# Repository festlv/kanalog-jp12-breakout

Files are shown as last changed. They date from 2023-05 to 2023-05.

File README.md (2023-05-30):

KFlop KAnalog JP12 breakout
==================================

KAnalog board has a connector JP12 with 8 outputs and 8 inputs. Since these IOs are unprotected, 3.3V LVTTL type, they 
are less than suitable for use for general purpose tasks (extra end stops, outputs etc).

This board breaks out these IOs as opto-isolated inputs and outputs, suitable for driving 24V loads and reading 24V inputs.

IO connection follows Kconnect conventions, see optoisolated inputs/outputs section of [this document](http://dynomotion.com/Help/SchematicsKonnect/ConnectorsKonnect.htm).

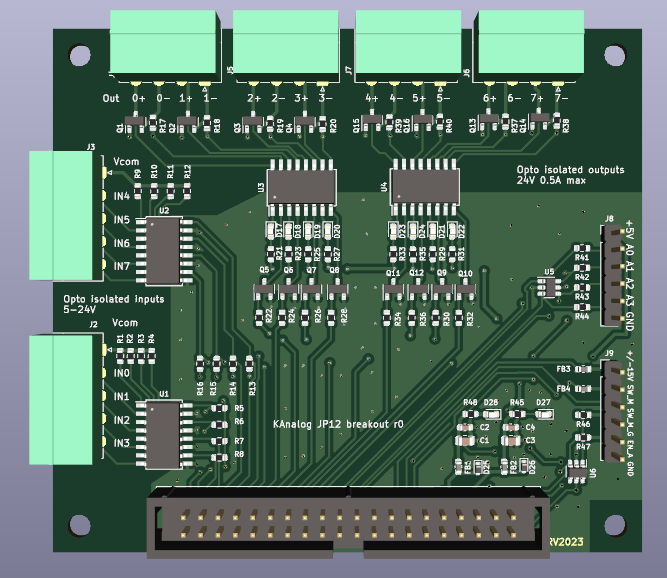
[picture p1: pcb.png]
pcb image


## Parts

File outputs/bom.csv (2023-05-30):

Source: | /home/reinis/Sync/ee/kanalog-jp12-breakout/kanalog-jp12-breakout.kicad_sch
Date: | trešdiena, 2023. gada 31. maijs, 02:11:31
Tool: | Eeschema 7.0.5-4d25ed1034~172~ubuntu20.04.1
Generator: | /usr/share/kicad/plugins/bom_csv_grouped_by_value.py
Component Count: | 99
Collated Components:
Item | Qty | Reference(s) | Value | LibPart | Footprint | Datasheet | DNP | LCSC# | MPN | Manufacturer
1 | 2 | C1, C3 | 10uF | Device:C_Small | Capacitor_SMD:C_0805_2012Metric | ~ |  | C17024 | CL21A106KPFNNNE | Samsung
2 | 2 | C2, C4 | 0.1uF | Device:C_Small | Capacitor_SMD:C_0603_1608Metric | ~
3 | 10 | D17, D18, D19, D20, D21, D22, D23, D24, D27, D28 | LED_GREEN | hadv-ui:LED_GREEN | LED_SMD:LED_0603_1608Metric | ~ |  | C434423 | SZYY0603YG | Yongyu Photoelectric
4 | 1 | D25 | BSD5C031V | hadv-protection:BSD5C031V | Diode_SMD:D_SOD-523 | https://datasheet.lcsc.com/lcsc/1912111437_BORN-BSD5C031V_C151984.pdf |  | C151984 | BSD5C031V | BORN
5 | 1 | D26 | PESD5V0S1BBN | hadv-protection:PESD5V0S1BBN | Diode_SMD:D_SOD-523 | https://datasheet.lcsc.com/lcsc/1912111437_BORN-PESD5V0S1BBN_C314264.pdf |  | C314264 | PESD5V0S1BBN | BORN
6 | 4 | FB1, FB2, FB3, FB4 | FB_100R_3A | hadv-passives:FB_100R_3A | Inductor_SMD:L_0603_1608Metric | ~ |  | C96995 | UPZ1608E101-3R0TF | Sunlord
7 | 1 | J1 | Conn_02x20_Odd_Even | Connector_Generic:Conn_02x20_Odd_Even | Connector_IDC:IDC-Header_2x20_P2.54mm_Vertical | ~ |  | C2962248 | X1270WR-2x20A-6TV01 | XKB
8 | 2 | J2, J3 | TERM-BLK-5H | hadv-connectors:TERM-BLK-5H | Connector_Phoenix_MC:PhoenixContact_MC_1,5_5-G-3.5_1x05_P3.50mm_Horizontal | ~ |  | C441174 | KF2EDGR-3.5-5P | Cixi Kefa Elec
9 | 4 | J4, J5, J6, J7 | TERM-BLK-4H | hadv-connectors:TERM-BLK-4H | Connector_Phoenix_MC:PhoenixContact_MC_1,5_4-G-3.5_1x04_P3.50mm_Horizontal | ~ |  | C441173 | KF2EDGR-3.5-4P | Cixi Kefa Elec
10 | 2 | J8, J9 | Conn_01x06 | Connector_Generic:Conn_01x06 | Connector_PinHeader_2.54mm:PinHeader_1x06_P2.54mm_Vertical | ~
11 | 8 | Q1, Q2, Q3, Q4, Q13, Q14, Q15, Q16 | DSS4240T | hadv-transistors:DSS4240T | Package_TO_SOT_SMD:SOT-23 | https://datasheet.lcsc.com/lcsc/1809081612_Diodes-Incorporated-DSS4240T-7_C151399.pdf |  | C151399 | DSS4240T-7 | Diodes Inc
12 | 8 | Q5, Q6, Q7, Q8, Q9, Q10, Q11, Q12 | SS8050 | hadv-transistors:SS8050 | Package_TO_SOT_SMD:SOT-23 | ~ |  | C2150 | SS8050 | Jiangsu Changjing Electronics
13 | 10 | R1, R2, R3, R4, R9, R10, R11, R12, R45, R48 | 4.12K | Device:R_Small | Resistor_SMD:R_0603_1608Metric | ~ |  | C23041 | 0603WAF4121T5E | Uniroyal
14 | 8 | R5, R6, R7, R8, R13, R14, R15, R16 | 10K | Device:R_Small | Resistor_SMD:R_0603_1608Metric | ~ |  | C25804 | 0603WAF1002T5E | Uniroyal
15 | 8 | R17, R18, R19, R20, R37, R38, R39, R40 | 220R | Device:R_Small | Resistor_SMD:R_0603_1608Metric | ~ |  | C22962 | 0603WAF2200T5E | Uniroyal
16 | 16 | R21, R22, R23, R24, R25, R26, R27, R28, R29, R30, R31, R32, R33, R34, R35, R36 | 330R | Device:R_Small | Resistor_SMD:R_0603_1608Metric | ~ |  | C23138 | 0603WAF3300T5E | Uniroyal
17 | 6 | R41, R42, R43, R44, R46, R47 | 100R | Device:R_Small | Resistor_SMD:R_0603_1608Metric | ~ |  | C22775 | 0603WAF1000T5E | Uniroyal
18 | 4 | U1, U2, U3, U4 | ELQ3H4 | hadv-buffers-translators:ELQ3H4 | Package_SO:SOIC-16W_5.3x10.2mm_P1.27mm | https://datasheet.lcsc.com/lcsc/1810301025_Everlight-Elec-ELQ3H4-TA-G_C150957.pdf |  | C150957 | ELQ3H4(TA)-G | Everlight Elec
19 | 2 | U5, U6 | USBLC6-4SC6 | hadv-protection:USBLC6-4SC6 | Package_TO_SOT_SMD:SOT-23-6 | https://www.st.com/resource/en/datasheet/usblc6-4.pdf |  | C5197386 | USBLC6-4SC6 | TECH PUBLIC

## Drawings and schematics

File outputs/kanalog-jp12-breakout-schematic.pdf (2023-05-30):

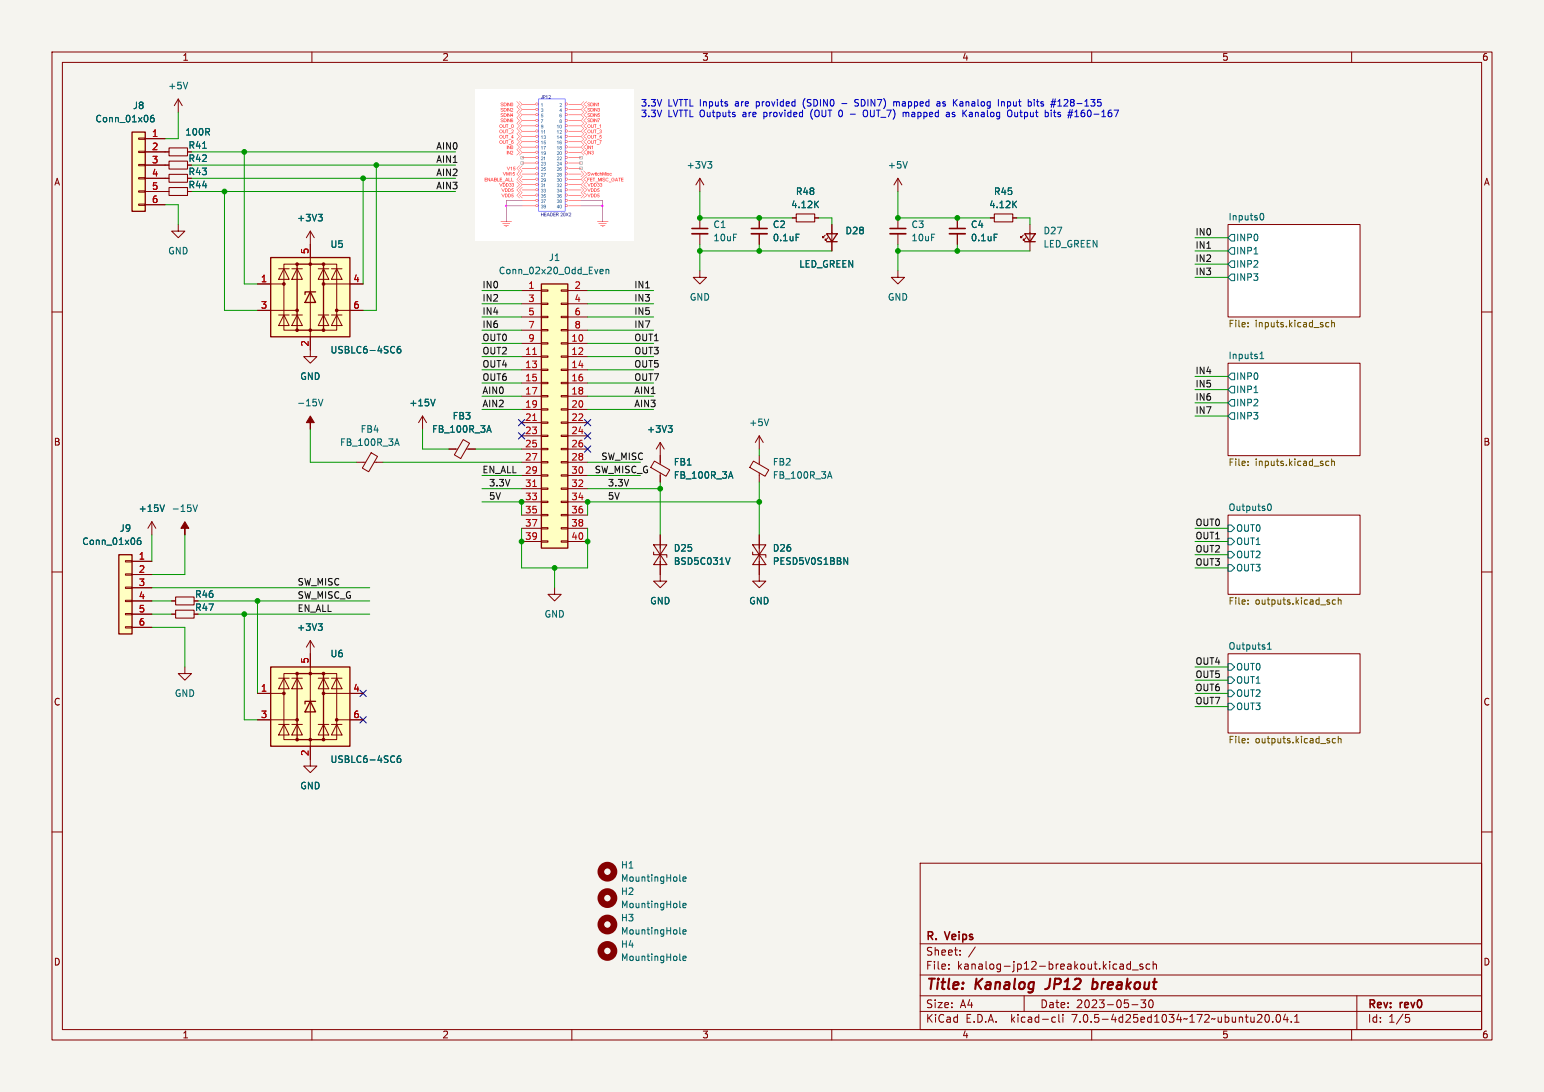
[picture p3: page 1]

3.3V LVTTL Inputs are provided (SDIN0 - SDIN7) mapped as Kanalog Input bits #128-135

Inputs1 File: inputs.kicad_sch OUT0 OUT1 OUT2 OUT3 Outputs0 File: outputs.kicad_sch OUT0 OUT1 OUT2 OUT3 Outputs1 File: outputs.kicad_sch GND

H1 MountingHole H3 MountingHole H2 MountingHole H4 MountingHole

Id: 1/5 Title: Kanalog JP12 breakout File: kanalog-jp12-breakout.kicad_sch Sheet: / R. Veips

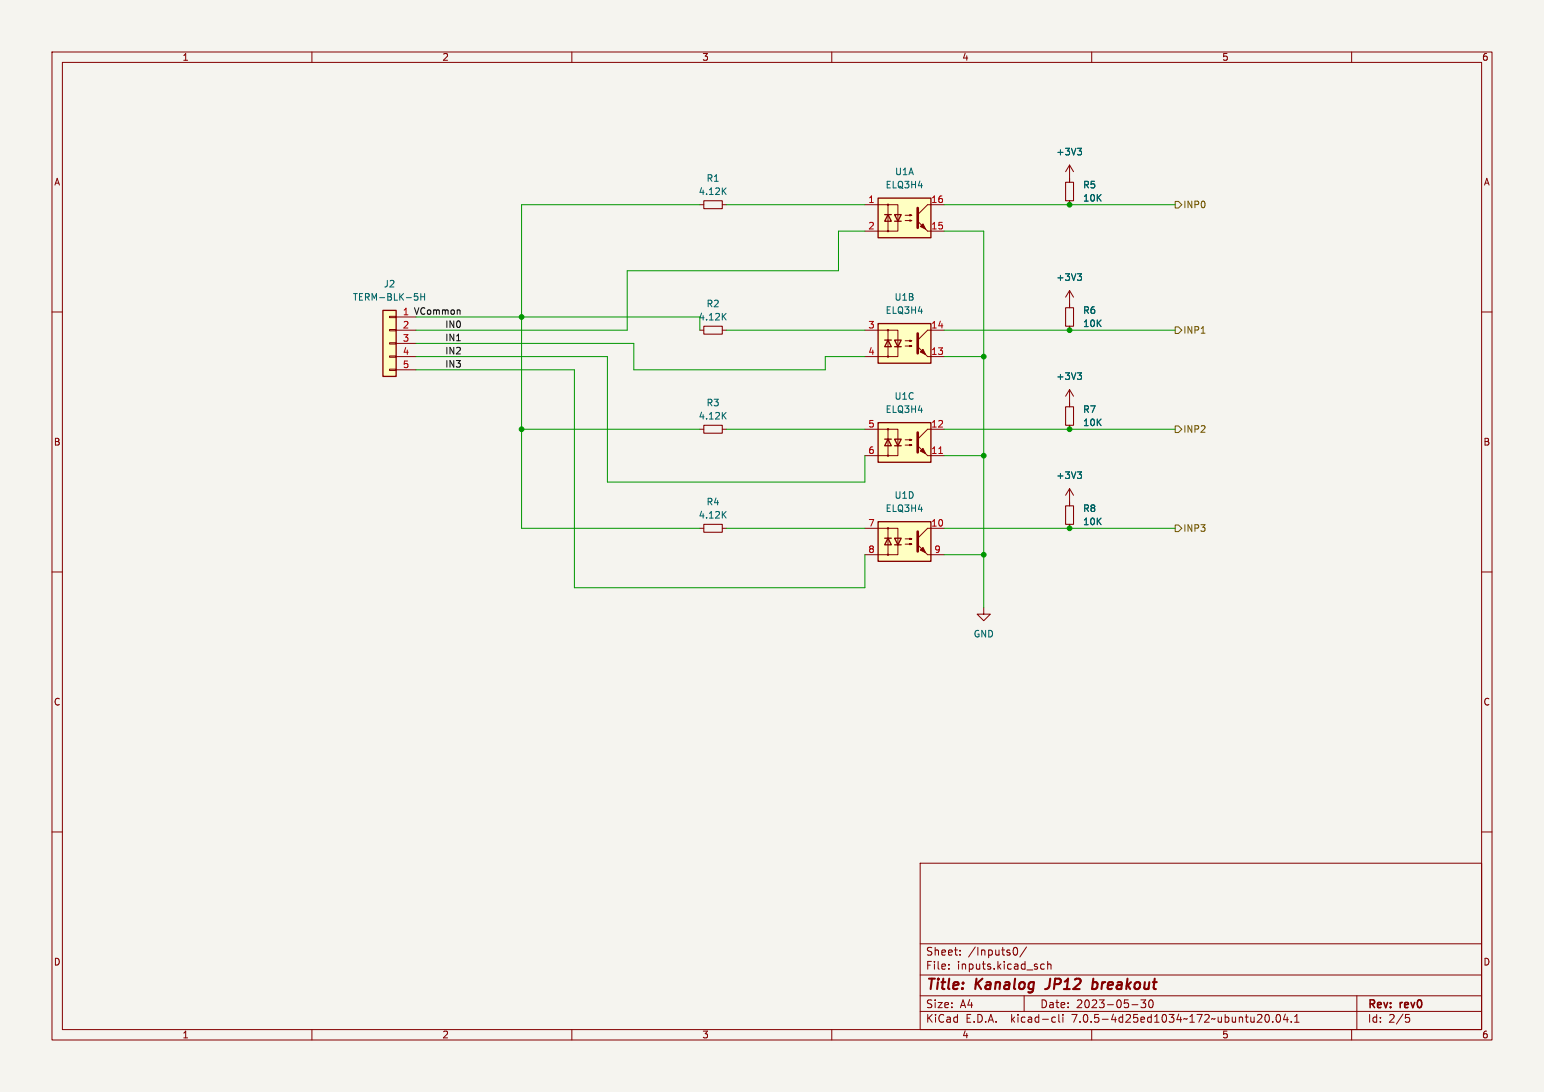
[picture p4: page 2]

4 IN2

Id: 2/5 Title: Kanalog JP12 breakout File: inputs.kicad_sch Sheet: /Inputs0/

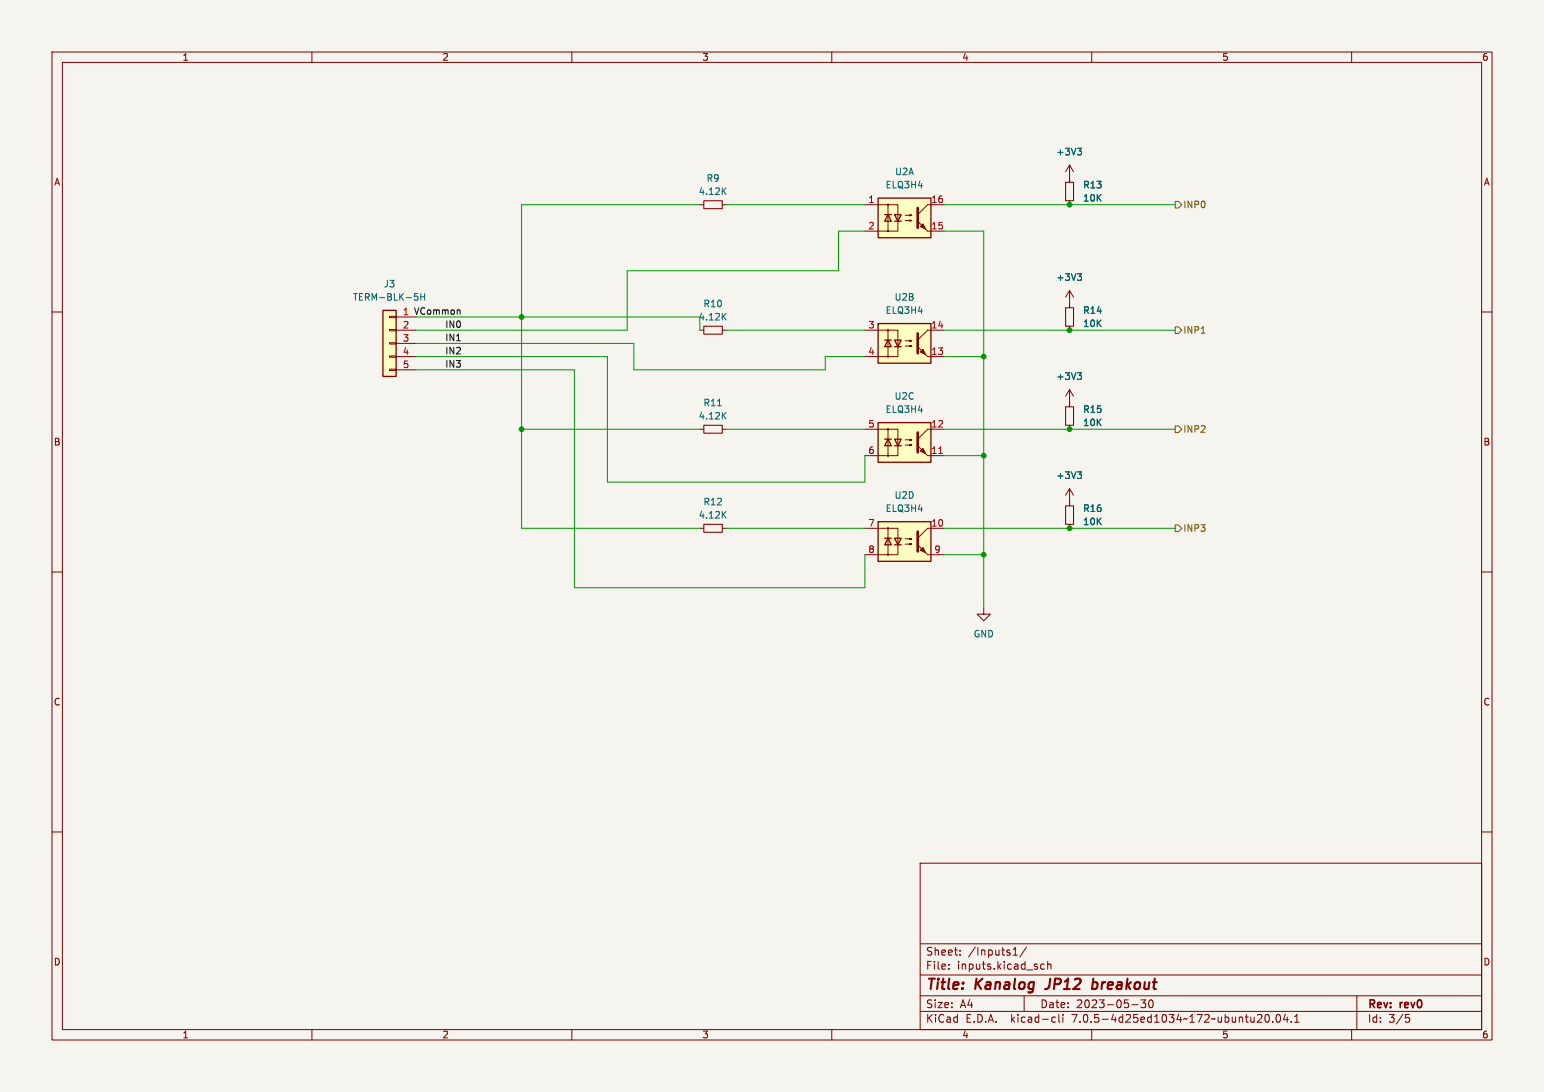
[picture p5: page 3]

4 IN2

Id: 3/5 Title: Kanalog JP12 breakout File: inputs.kicad_sch Sheet: /Inputs1/

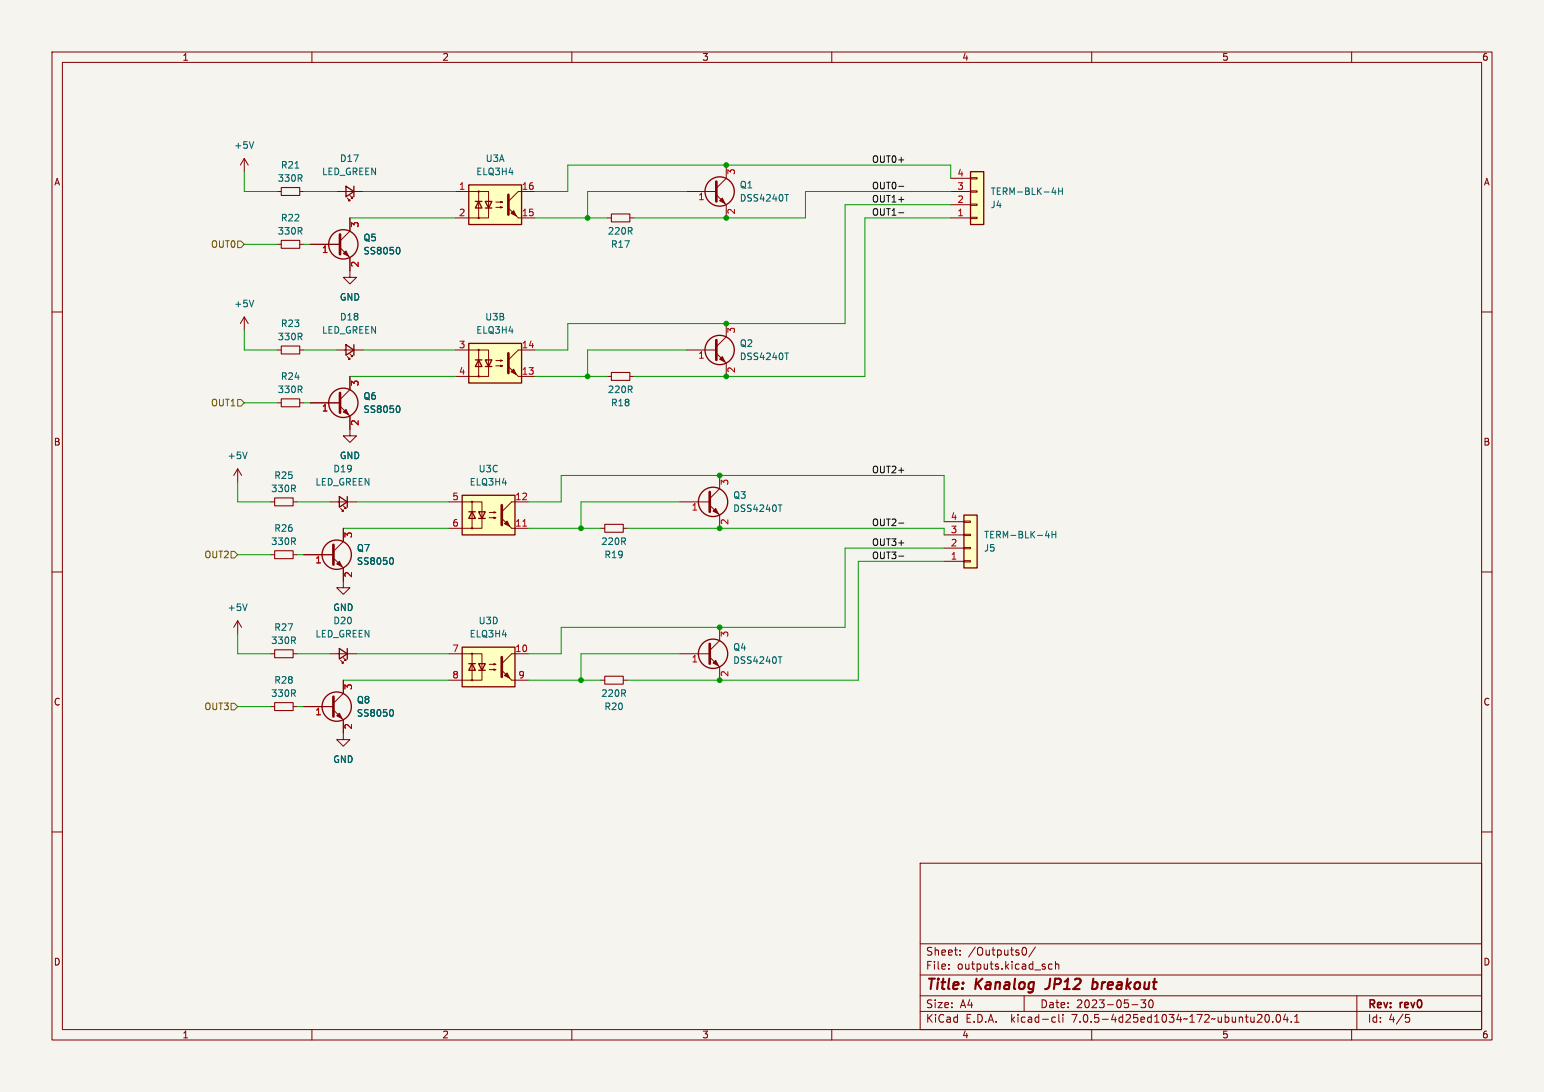
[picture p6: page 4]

Id: 4/5 Title: Kanalog JP12 breakout File: outputs.kicad_sch Sheet: /Outputs0/

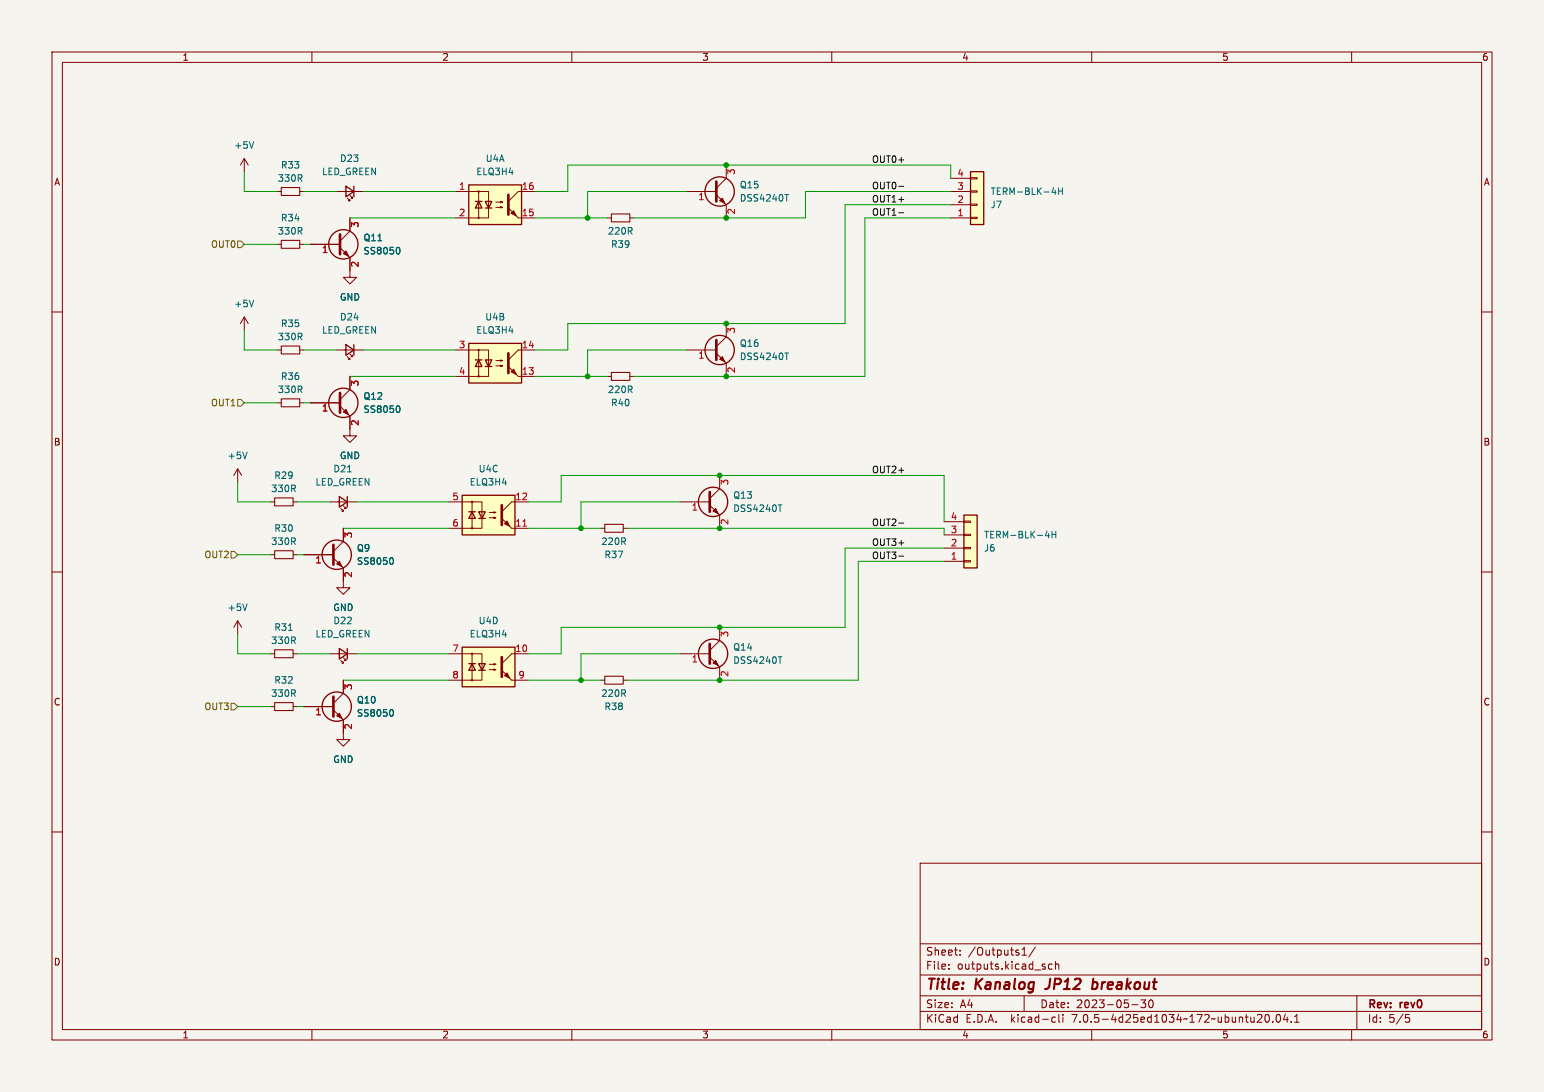
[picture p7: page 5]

Id: 5/5 Title: Kanalog JP12 breakout File: outputs.kicad_sch Sheet: /Outputs1/ R30

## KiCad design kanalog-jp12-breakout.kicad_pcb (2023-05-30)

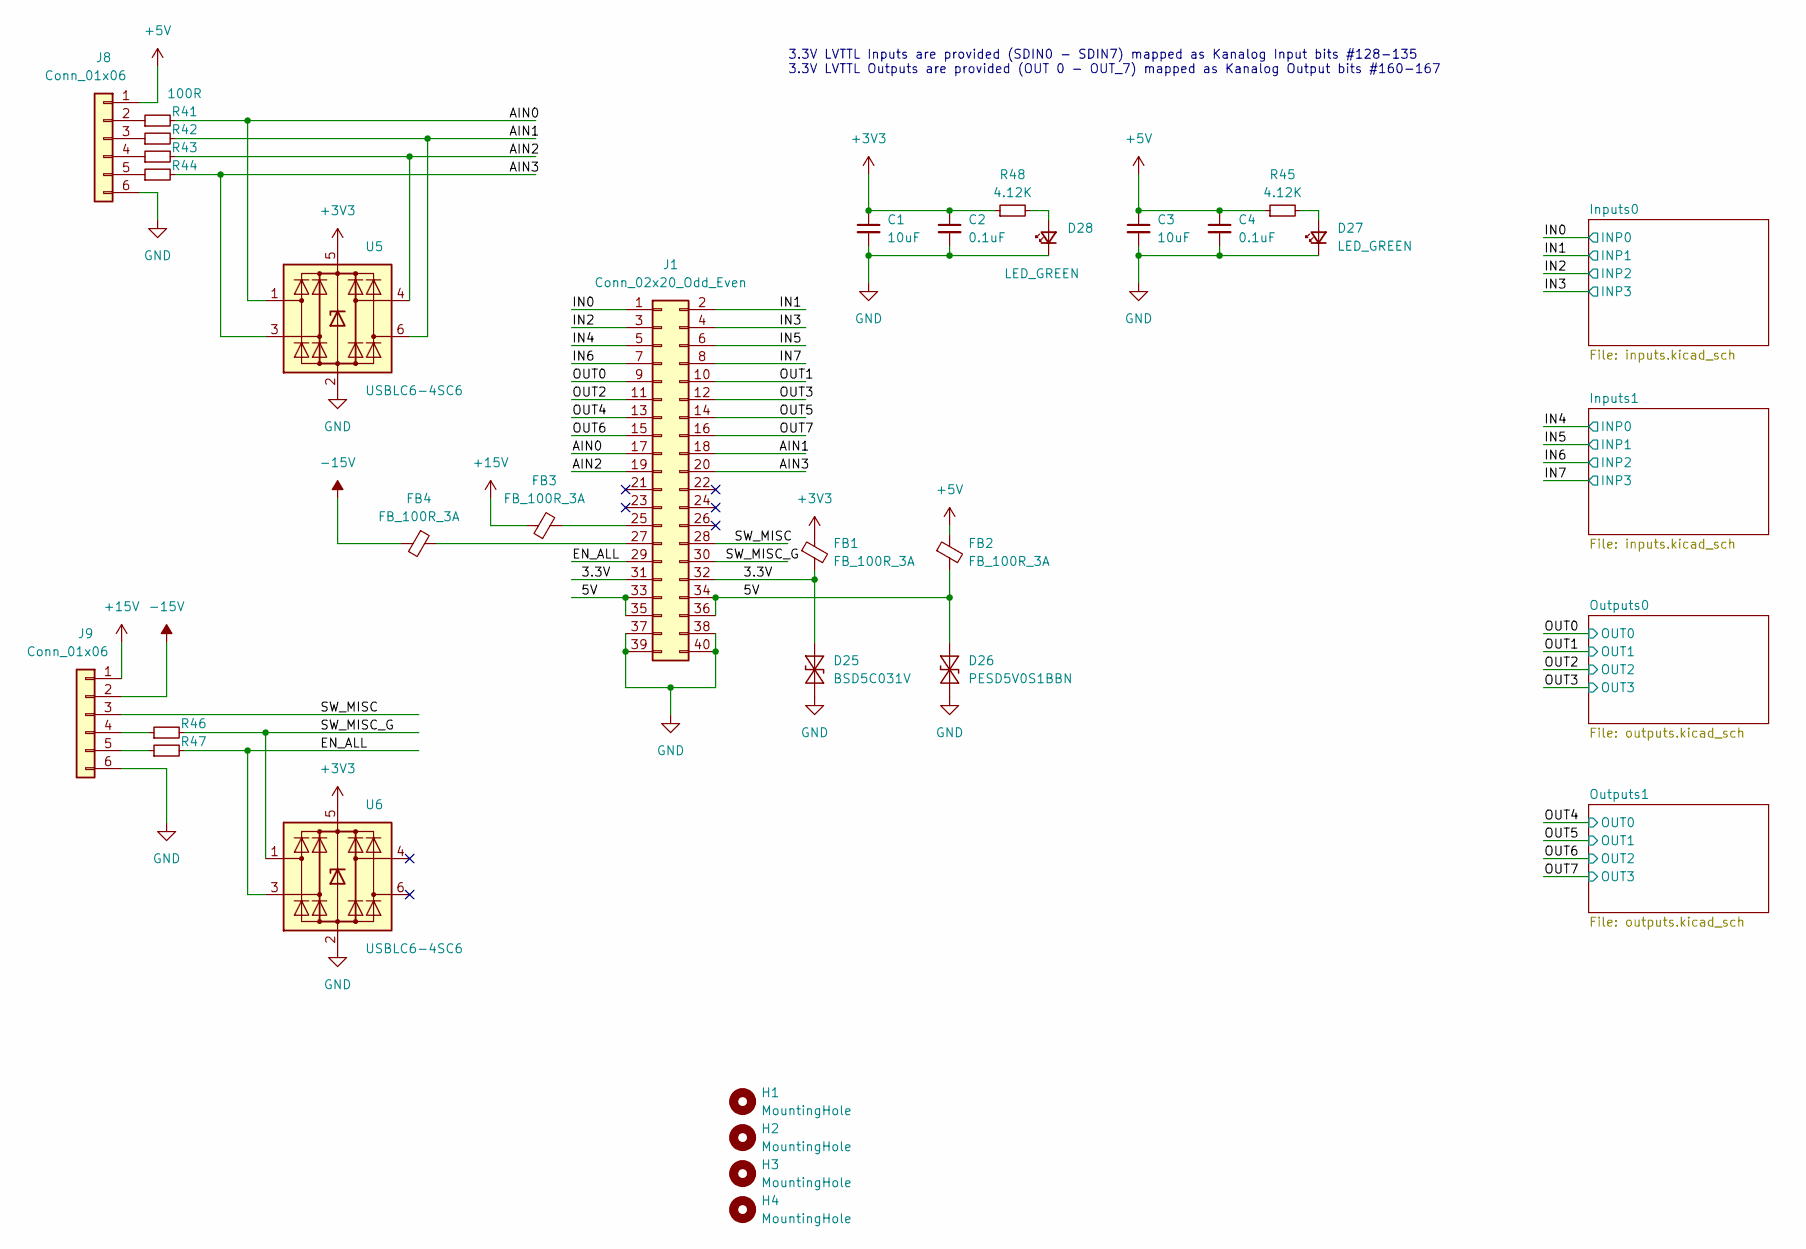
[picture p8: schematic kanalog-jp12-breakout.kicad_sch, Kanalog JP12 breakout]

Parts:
C1, C3: 10uF; C_0805_2012Metric; MPN CL21A106KPFNNNE; LCSC# C17024
C2, C4: 0.1uF; C_0603_1608Metric
D25: BSD5C031V; D_SOD-523; MPN BSD5C031V; LCSC# C151984
D26: PESD5V0S1BBN; D_SOD-523; MPN PESD5V0S1BBN; LCSC# C314264
D27, D28: LED_GREEN; LED_0603_1608Metric; MPN SZYY0603YG; LCSC# C434423
FB1, FB2, FB3, FB4: FB_100R_3A; L_0603_1608Metric; MPN UPZ1608E101-3R0TF; LCSC# C96995
H1, H2, H3, H4: MountingHole; MountingHole_3.5mm
J1: Conn_02x20_Odd_Even; IDC-Header_2x20_P2.54mm_Vertical; MPN X1270WR-2x20A-6TV01; LCSC# C2962248
J8, J9: Conn_01x06; PinHeader_1x06_P2.54mm_Vertical
R41, R42, R43, R44, R46, R47: 100R; R_0603_1608Metric; MPN 0603WAF1000T5E; LCSC# C22775
R45, R48: 4.12K; R_0603_1608Metric; MPN 0603WAF4121T5E; LCSC# C23041
U5, U6: USBLC6-4SC6; SOT-23-6; MPN USBLC6-4SC6; LCSC# C5197386

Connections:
+3V3: C1.1, C2.1, FB1.1, R48.1, U5.5 (VBUS), U6.5 (VBUS); also elsewhere on the board
+5V: C3.1, C4.1, FB2.1, J8.1, R45.1; also elsewhere on the board
+15V: FB3.1, J9.1
-15V: FB4.2, J9.2
/3.3V: D25.2 (A2), FB1.2, J1.31, J1.32
/5V: D26.2 (A2), FB2.2, J1.33, J1.34, J1.35, J1.36
/AIN0: J1.17, R41.2, U5.1 (I/O1)
/AIN1: J1.18, R42.2, U5.6 (I/O4)
/AIN2: J1.19, R43.2, U5.4 (I/O3)
/AIN3: J1.20, R44.2, U5.3 (I/O2)
/EN_ALL: J1.29, R47.2, U6.3 (I/O2)
/IN0: J1.1; also elsewhere on the board
/IN1: J1.2; also elsewhere on the board
/IN2: J1.3; also elsewhere on the board
/IN3: J1.4; also elsewhere on the board
/IN4: J1.5; also elsewhere on the board
/IN5: J1.6; also elsewhere on the board
/IN6: J1.7; also elsewhere on the board
/IN7: J1.8; also elsewhere on the board
/OUT0: J1.9; also elsewhere on the board
/OUT1: J1.10; also elsewhere on the board
/OUT2: J1.11; also elsewhere on the board
/OUT3: J1.12; also elsewhere on the board
/OUT4: J1.13; also elsewhere on the board
/OUT5: J1.14; also elsewhere on the board
/OUT6: J1.15; also elsewhere on the board
/OUT7: J1.16; also elsewhere on the board
/SW_MISC: J1.28, J9.3
/SW_MISC_G: J1.30, R46.2, U6.1 (I/O1)
GND: C1.2, C2.2, C3.2, C4.2, D25.1 (A1), D26.1 (A1), D27.1 (K), D28.1 (K), J1.37, J1.38, J1.39, J1.40, J8.6, J9.6, U5.2 (GND), U6.2 (GND); also elsewhere on the board
unnamed: D27.2 (A), R45.2
unnamed: D28.2 (A), R48.2
unnamed: FB3.2, J1.25
unnamed: FB4.1, J1.27
unnamed: J8.2, R41.1
unnamed: J8.3, R42.1
unnamed: J8.4, R43.1
unnamed: J8.5, R44.1
unnamed: J9.4, R46.1
unnamed: J9.5, R47.1

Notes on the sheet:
3.3V LVTTL Inputs are provided (SDIN0 - SDIN7) mapped as Kanalog Input bits #128-135 3.3V LVTTL Outputs are provided (OUT 0 - OUT_7) mapped as Kanalog Output bits #160-167

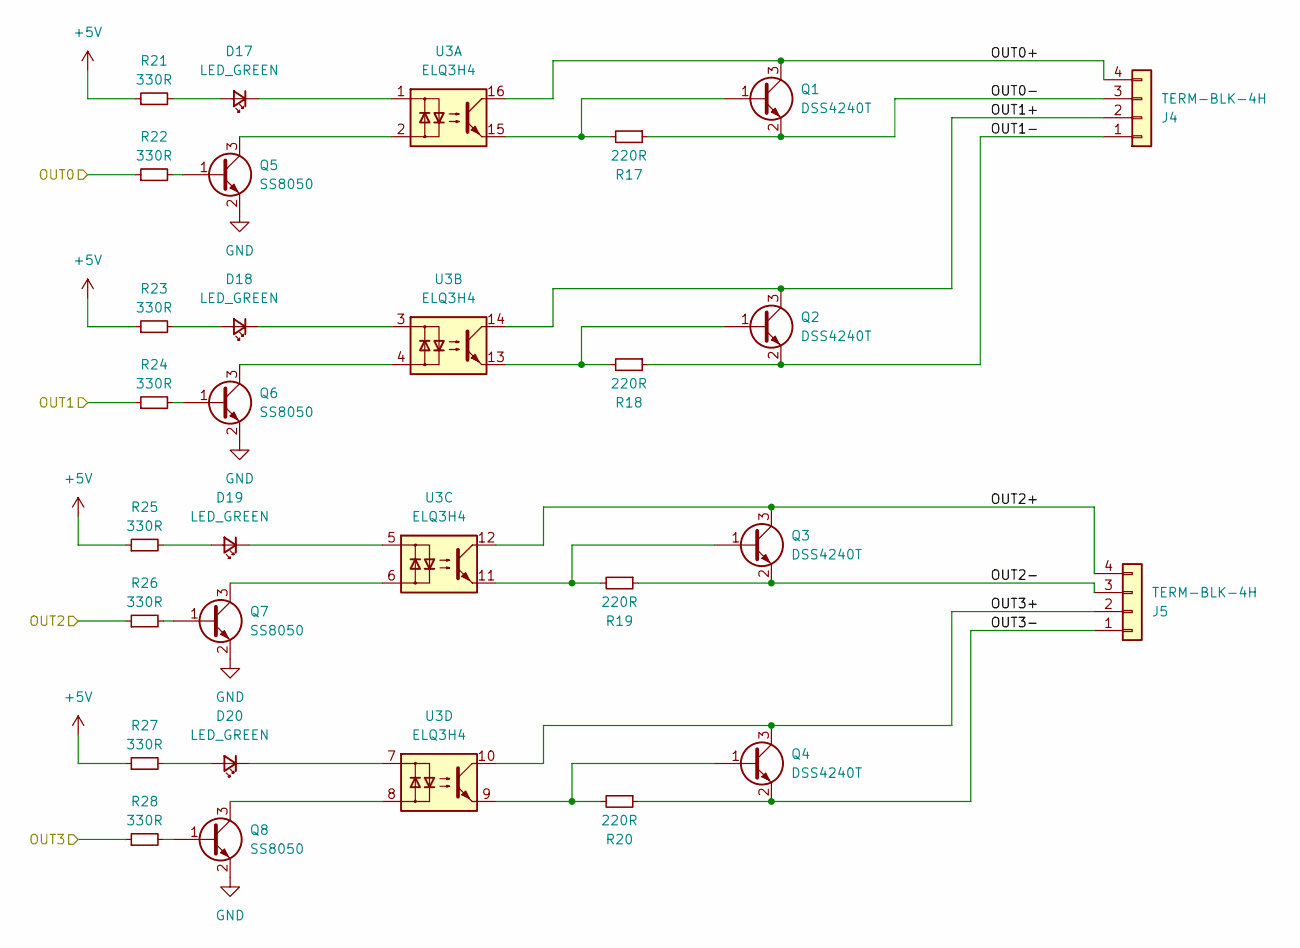
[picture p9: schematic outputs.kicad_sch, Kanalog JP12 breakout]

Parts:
D17, D18, D19, D20: LED_GREEN; LED_0603_1608Metric; MPN SZYY0603YG; LCSC# C434423
J4, J5: TERM-BLK-4H; PhoenixContact_MC_1,5_4-G-3.5_1x04_P3.50mm_Horizontal; MPN KF2EDGR-3.5-4P; LCSC# C441173
Q1, Q2, Q3, Q4: DSS4240T; SOT-23; MPN DSS4240T-7; LCSC# C151399
Q5, Q6, Q7, Q8: SS8050; SOT-23; MPN SS8050; LCSC# C2150
R17, R18, R19, R20: 220R; R_0603_1608Metric; MPN 0603WAF2200T5E; LCSC# C22962
R21, R22, R23, R24, R25, R26, R27, R28: 330R; R_0603_1608Metric; MPN 0603WAF3300T5E; LCSC# C23138
U3: ELQ3H4; SOIC-16W_5.3x10.2mm_P1.27mm; MPN ELQ3H4(TA)-G; LCSC# C150957

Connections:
+5V: R21.1, R23.1, R25.1, R27.1; also elsewhere on the board
/OUT0: R22.1; also elsewhere on the board
/OUT1: R24.1; also elsewhere on the board
/OUT2: R26.1; also elsewhere on the board
/OUT3: R28.1; also elsewhere on the board
/Outputs0/OUT0+: J4.4, Q1.3 (C), U3.16
/Outputs0/OUT0-: J4.3, Q1.2 (E), R17.1
/Outputs0/OUT1+: J4.2, Q2.3 (C), U3.14
/Outputs0/OUT1-: J4.1, Q2.2 (E), R18.1
/Outputs0/OUT2+: J5.4, Q3.3 (C), U3.12
/Outputs0/OUT2-: J5.3, Q3.2 (E), R19.1
/Outputs0/OUT3+: J5.2, Q4.3 (C), U3.10
/Outputs0/OUT3-: J5.1, Q4.2 (E), R20.1
GND: Q5.2 (E), Q6.2 (E), Q7.2 (E), Q8.2 (E); also elsewhere on the board
unnamed: D17.2 (A), R21.2
unnamed: D17.1 (K), U3.1
unnamed: D18.2 (A), R23.2
unnamed: D18.1 (K), U3.3
unnamed: D19.2 (A), R25.2
unnamed: D19.1 (K), U3.5
unnamed: D20.2 (A), R27.2
unnamed: D20.1 (K), U3.7
unnamed: Q1.1 (B), R17.2, U3.15
unnamed: Q2.1 (B), R18.2, U3.13
unnamed: Q3.1 (B), R19.2, U3.11
unnamed: Q4.1 (B), R20.2, U3.9
unnamed: Q5.1 (B), R22.2
unnamed: Q5.3 (C), U3.2
unnamed: Q6.1 (B), R24.2
unnamed: Q6.3 (C), U3.4
unnamed: Q7.1 (B), R26.2
unnamed: Q7.3 (C), U3.6
unnamed: Q8.1 (B), R28.2
unnamed: Q8.3 (C), U3.8

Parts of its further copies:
D21, D22, D23, D24: LED_GREEN; LED_0603_1608Metric; MPN SZYY0603YG; LCSC# C434423
J6, J7: TERM-BLK-4H; PhoenixContact_MC_1,5_4-G-3.5_1x04_P3.50mm_Horizontal; MPN KF2EDGR-3.5-4P; LCSC# C441173
Q9, Q10, Q11, Q12: SS8050; SOT-23; MPN SS8050; LCSC# C2150
Q13, Q14, Q15, Q16: DSS4240T; SOT-23; MPN DSS4240T-7; LCSC# C151399
R29, R30, R31, R32, R33, R34, R35, R36: 330R; R_0603_1608Metric; MPN 0603WAF3300T5E; LCSC# C23138
R37, R38, R39, R40: 220R; R_0603_1608Metric; MPN 0603WAF2200T5E; LCSC# C22962
U4: ELQ3H4; SOIC-16W_5.3x10.2mm_P1.27mm; MPN ELQ3H4(TA)-G; LCSC# C150957

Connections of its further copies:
+5V: R29.1, R31.1, R33.1, R35.1; also elsewhere on the board
/OUT4: R34.1; also elsewhere on the board
/OUT5: R36.1; also elsewhere on the board
/OUT6: R30.1; also elsewhere on the board
/OUT7: R32.1; also elsewhere on the board
/Outputs1/OUT0+: J7.4, Q15.3 (C), U4.16
/Outputs1/OUT0-: J7.3, Q15.2 (E), R39.1
/Outputs1/OUT1+: J7.2, Q16.3 (C), U4.14
/Outputs1/OUT1-: J7.1, Q16.2 (E), R40.1
/Outputs1/OUT2+: J6.4, Q13.3 (C), U4.12
/Outputs1/OUT2-: J6.3, Q13.2 (E), R37.1
/Outputs1/OUT3+: J6.2, Q14.3 (C), U4.10
/Outputs1/OUT3-: J6.1, Q14.2 (E), R38.1
GND: Q9.2 (E), Q10.2 (E), Q11.2 (E), Q12.2 (E); also elsewhere on the board
unnamed: D21.2 (A), R29.2
unnamed: D21.1 (K), U4.5
unnamed: D22.2 (A), R31.2
unnamed: D22.1 (K), U4.7
unnamed: D23.2 (A), R33.2
unnamed: D23.1 (K), U4.1
unnamed: D24.2 (A), R35.2
unnamed: D24.1 (K), U4.3
unnamed: Q9.1 (B), R30.2
unnamed: Q9.3 (C), U4.6
unnamed: Q10.1 (B), R32.2
unnamed: Q10.3 (C), U4.8
unnamed: Q11.1 (B), R34.2
unnamed: Q11.3 (C), U4.2
unnamed: Q12.1 (B), R36.2
unnamed: Q12.3 (C), U4.4
unnamed: Q13.1 (B), R37.2, U4.11
unnamed: Q14.1 (B), R38.2, U4.9
unnamed: Q15.1 (B), R39.2, U4.15
unnamed: Q16.1 (B), R40.2, U4.13

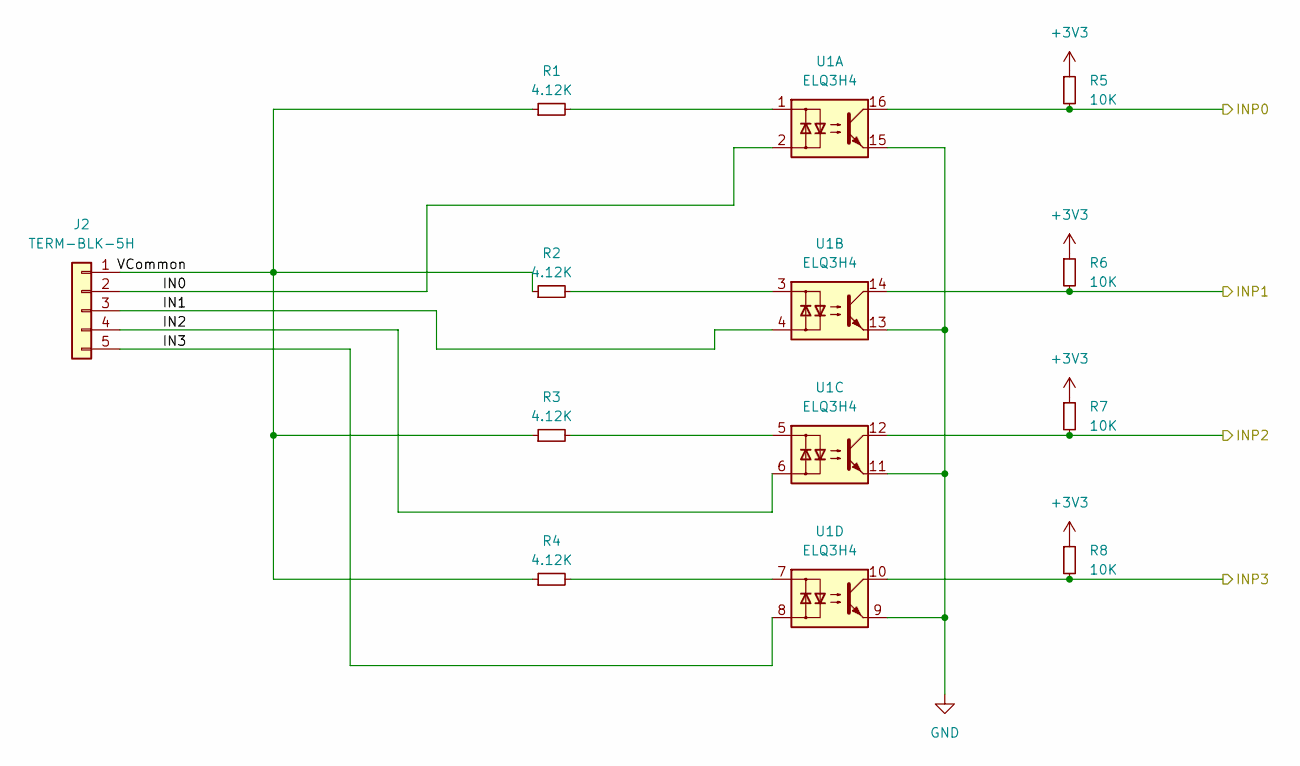
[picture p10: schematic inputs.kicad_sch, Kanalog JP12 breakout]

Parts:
J2: TERM-BLK-5H; PhoenixContact_MC_1,5_5-G-3.5_1x05_P3.50mm_Horizontal; MPN KF2EDGR-3.5-5P; LCSC# C441174
R1, R2, R3, R4: 4.12K; R_0603_1608Metric; MPN 0603WAF4121T5E; LCSC# C23041
R5, R6, R7, R8: 10K; R_0603_1608Metric; MPN 0603WAF1002T5E; LCSC# C25804
U1: ELQ3H4; SOIC-16W_5.3x10.2mm_P1.27mm; MPN ELQ3H4(TA)-G; LCSC# C150957

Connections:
+3V3: R5.1, R6.1, R7.1, R8.1; also elsewhere on the board
/IN0: R5.2, U1.16; also elsewhere on the board
/IN1: R6.2, U1.14; also elsewhere on the board
/IN2: R7.2, U1.12; also elsewhere on the board
/IN3: R8.2, U1.10; also elsewhere on the board
/Inputs0/IN0: J2.2, U1.2
/Inputs0/IN1: J2.3, U1.4
/Inputs0/IN2: J2.4, U1.6
/Inputs0/IN3: J2.5, U1.8
/Inputs0/VCommon: J2.1, R1.1, R2.1, R3.1, R4.1
GND: U1.9, U1.11, U1.13, U1.15; also elsewhere on the board
unnamed: R1.2, U1.1
unnamed: R2.2, U1.3
unnamed: R3.2, U1.5
unnamed: R4.2, U1.7

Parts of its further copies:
J3: TERM-BLK-5H; PhoenixContact_MC_1,5_5-G-3.5_1x05_P3.50mm_Horizontal; MPN KF2EDGR-3.5-5P; LCSC# C441174
R9, R10, R11, R12: 4.12K; R_0603_1608Metric; MPN 0603WAF4121T5E; LCSC# C23041
R13, R14, R15, R16: 10K; R_0603_1608Metric; MPN 0603WAF1002T5E; LCSC# C25804
U2: ELQ3H4; SOIC-16W_5.3x10.2mm_P1.27mm; MPN ELQ3H4(TA)-G; LCSC# C150957

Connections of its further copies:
+3V3: R13.1, R14.1, R15.1, R16.1; also elsewhere on the board
/IN4: R13.2, U2.16; also elsewhere on the board
/IN5: R14.2, U2.14; also elsewhere on the board
/IN6: R15.2, U2.12; also elsewhere on the board
/IN7: R16.2, U2.10; also elsewhere on the board
/Inputs1/IN0: J3.2, U2.2
/Inputs1/IN1: J3.3, U2.4
/Inputs1/IN2: J3.4, U2.6
/Inputs1/IN3: J3.5, U2.8
/Inputs1/VCommon: J3.1, R9.1, R10.1, R11.1, R12.1
GND: U2.9, U2.11, U2.13, U2.15; also elsewhere on the board
unnamed: R9.2, U2.1
unnamed: R10.2, U2.3
unnamed: R11.2, U2.5
unnamed: R12.2, U2.7

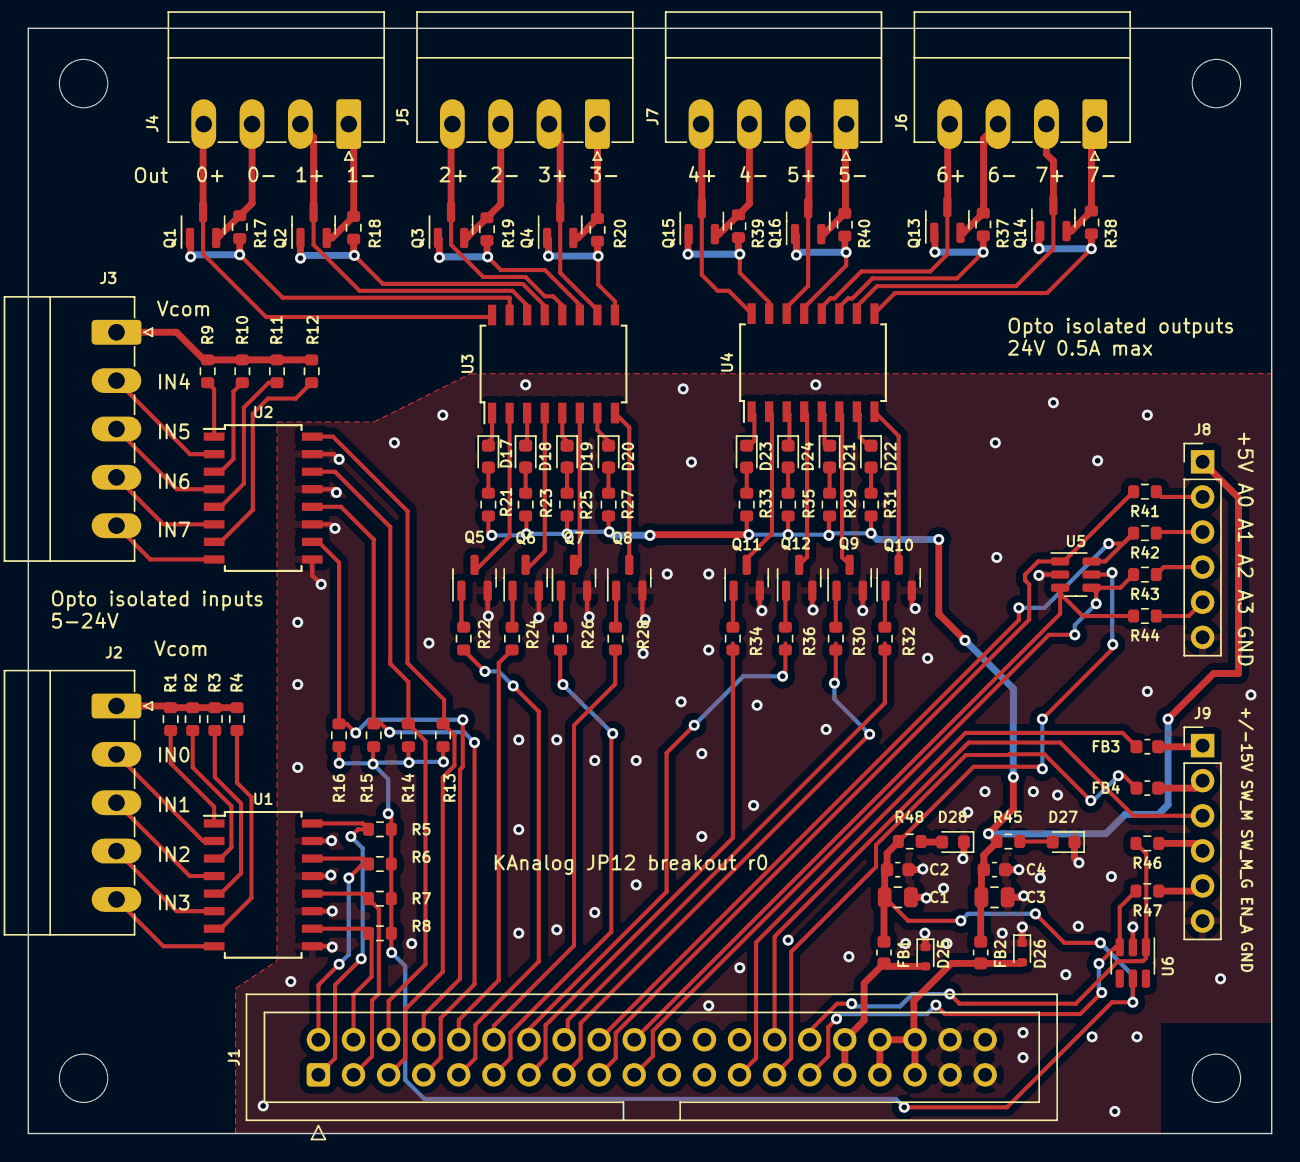
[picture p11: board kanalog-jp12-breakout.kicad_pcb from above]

Board: 2 copper layers, 90.0 x 80.0 mm, 103 parts (0 on the bottom side), 114 nets.
